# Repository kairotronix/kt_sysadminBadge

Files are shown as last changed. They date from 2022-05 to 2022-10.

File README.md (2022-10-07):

# SysAdmin Badge

This is the PCB design for the SysAdmin Day badge.

The badge design is inspired by deep thought, from The Hitchhiker's Guide to the Galaxy.

The LCD being used is a standard 1.3" 240x240 display from Ali Express. Searching `1.3 inch IPS display TFT LCD 1.3" Display Screen Module 240*240 ST7789 Drive IC SPI HD Full Color for IPS Display Module 240X240` and selecting the "welded" or "soldered" variety will yield the correct board. 

The soldered-on cable was chosen for cost reduction.



# What is the idea
In case of fire, a quick reaction is needed, but if you just woke up, if you are in the bathroom or in any compromising situation, the sysadmin must always respond to the user, and then fix the incident.

For this reason, we have designed a random excuse generator that will give you a perfect SLA, even in desperate moments.

Note: Answers may be satirical, so use at your own risk. 

## History
The System Administrator Appreciation Day, It is celebrated on the last Friday of July since the year 2000.

The holiday was started by a system administrator nicknamed Sleeping Beauty (AS). He got his inspiration from a Hewlett-Packard magazine ad, in which an administrator's co-workers gave him flowers and a fruit basket for setting up their new printers and a pillow to rest on in their spare time.

Wait… what exactly is SysAdmin Day? it’s only the single greatest 24 hours on the planet… and pretty much the most important holiday of the year. It’s also the perfect opportunity to pay tribute to the heroic men and women who, come rain or shine, prevent disasters, keep IT secure and put out tech fires left and right.

At this point, you may be thinking, “Great. I get it. My SysAdmin is a rock star. But now what?” Glad you asked! Proper observation of SysAdmin Day includes (but is not limited to):

Cake & Ice cream

Pizza

Cards

Gifts

Words of gratitude

Custom t-shirts celebrating the epic greatness of your SysAdmin

Balloons

Confetti

Did I say gifts

# Conclusion
Why make one badge electronic? Because is one good gift of your SysAdmin.

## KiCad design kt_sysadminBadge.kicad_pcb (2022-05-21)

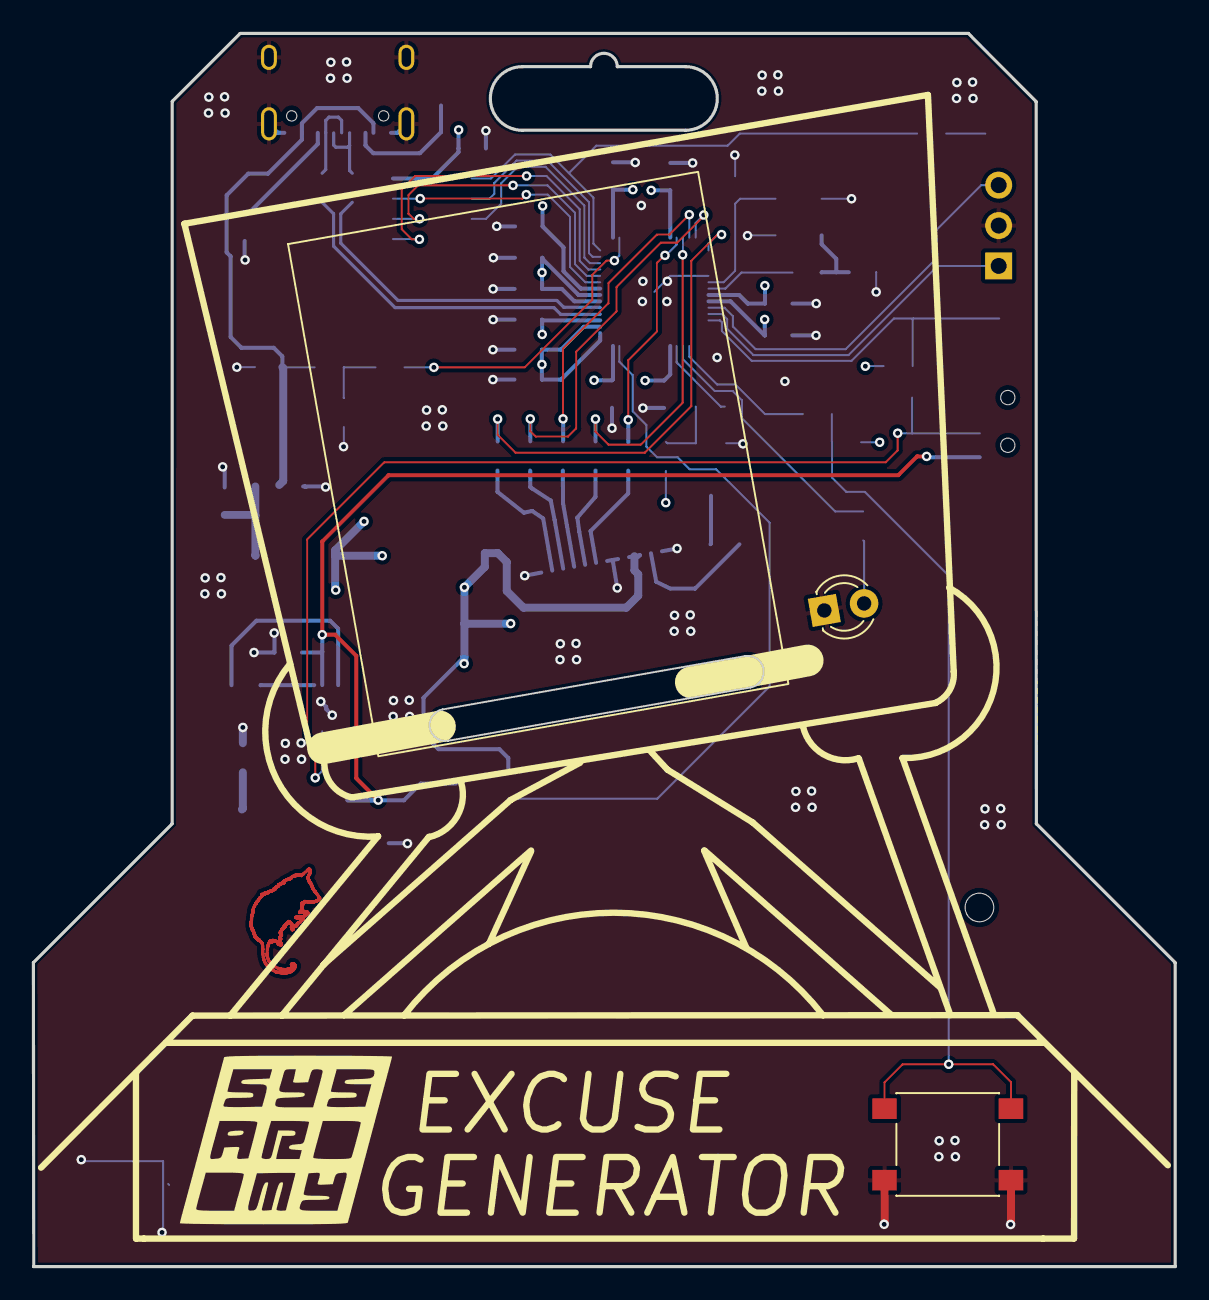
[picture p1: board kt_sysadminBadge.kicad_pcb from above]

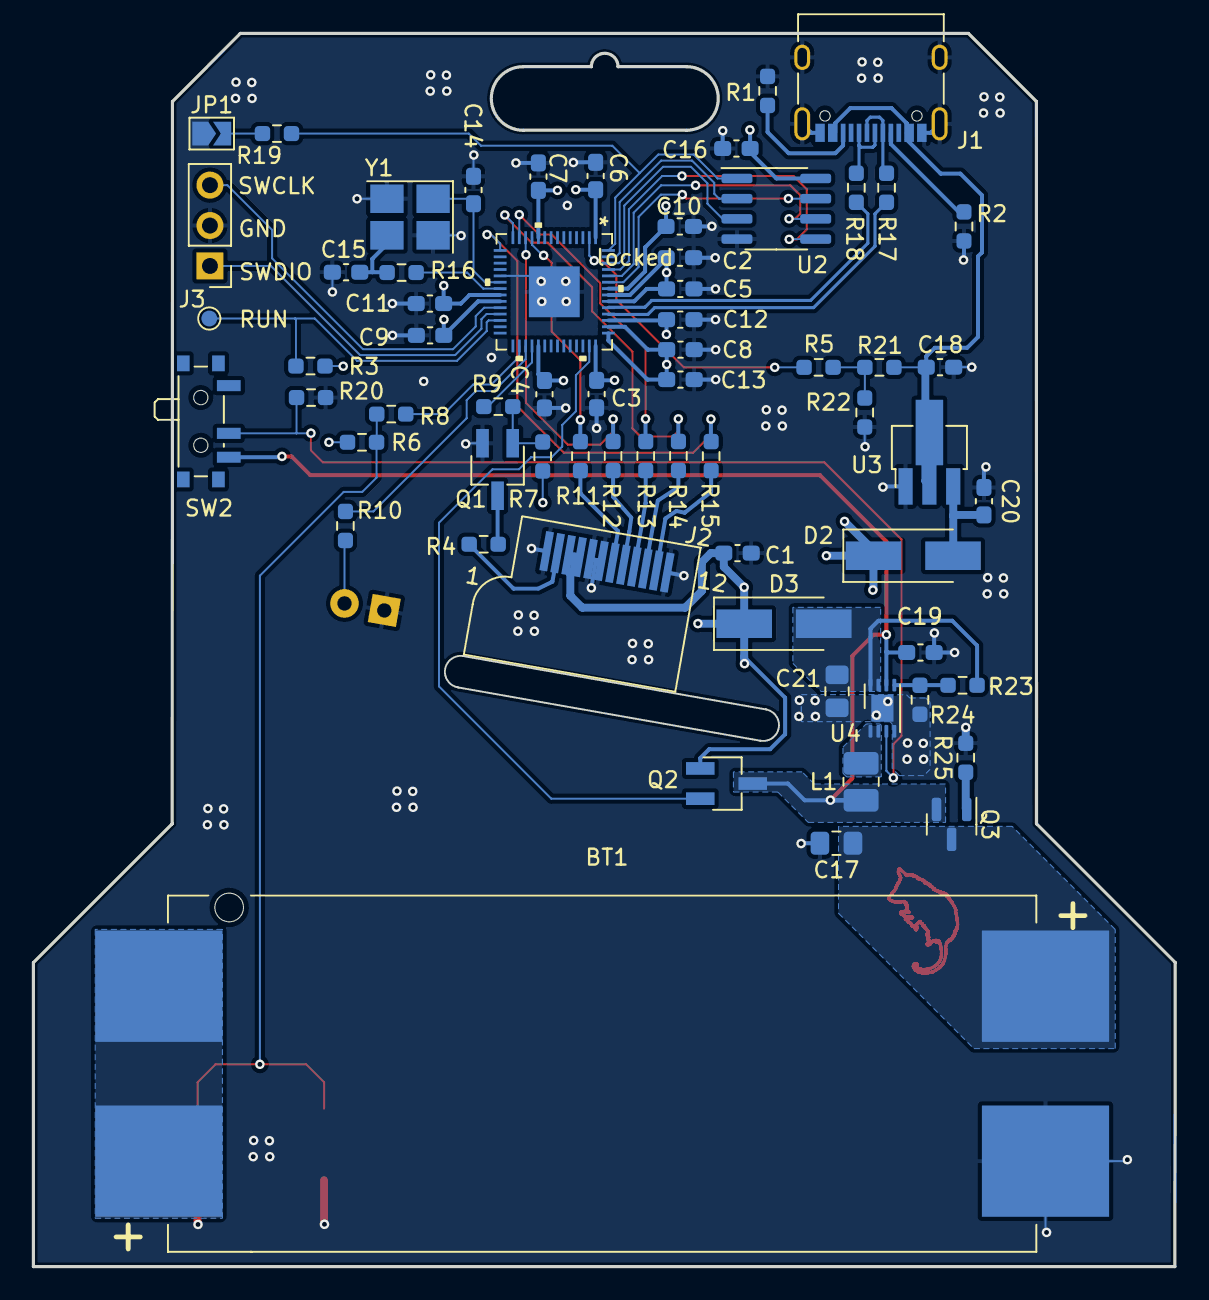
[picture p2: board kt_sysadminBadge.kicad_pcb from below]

Board: 4 copper layers, 71.8 x 77.5 mm, 66 parts (63 on the bottom side), 53 nets.

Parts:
BT1: Battery_4term; BH-AAA-B5AA001
C1, C2, C3, C4, C5, C6, C8, C9, C10, C11, C16: 100nF; C_0603_1608Metric_Pad1.08x0.95mm_HandSolder
C7, C12, C13: 2.2uF; C_0603_1608Metric_Pad1.08x0.95mm_HandSolder
C14, C15: 15pF; C_0603_1608Metric_Pad1.08x0.95mm_HandSolder
C17, C21: 22uF; C_0805_2012Metric_Pad1.18x1.45mm_HandSolder
C18, C19, C20: 1uF; C_0603_1608Metric_Pad1.08x0.95mm_HandSolder
D1: LED; LED_D3.0mm
D2, D3: D_Schottky; D_SMA_Handsoldering
J1: USB_C_Receptacle_USB2.0; USB_C_Receptacle_XKB_U262-16XN-4BVC11
J2: Conn_01x12; st7789-240-240
J3: Conn_01x03; PinHeader_1x03_P2.54mm_Vertical
JP1: Jumper_2_Open; SolderJumper-2_P1.3mm_Open_TrianglePad1.0x1.5mm
L1: 1.5uH; L_1008_2520Metric_Pad1.43x2.20mm_HandSolder
Q1: MMSS8050; SC-59_Handsoldering
Q2: Q_NMOS_GSD; SC-59_Handsoldering
Q3: DMG2301L-7; SOT-23
R1, R2: 5.1kR; R_0603_1608Metric_Pad0.98x0.95mm_HandSolder
R3, R6, R7: 10k; R_0603_1608Metric_Pad0.98x0.95mm_HandSolder
R4: 10R; R_0603_1608Metric_Pad0.98x0.95mm_HandSolder
R5, R8, R11, R12, R13, R14, R15: 0R; R_0603_1608Metric_Pad0.98x0.95mm_HandSolder
R9, R16, R19: 1kR; R_0603_1608Metric_Pad0.98x0.95mm_HandSolder
R10, R25: 330R; R_0603_1608Metric_Pad0.98x0.95mm_HandSolder
R17, R18: 27R; R_0603_1608Metric_Pad0.98x0.95mm_HandSolder
R20, R23: 1MR; R_0603_1608Metric_Pad0.98x0.95mm_HandSolder
R21: 100kR; R_0603_1608Metric_Pad0.98x0.95mm_HandSolder
R22: 150kR; R_0603_1608Metric_Pad0.98x0.95mm_HandSolder
R24: 500kR; R_0603_1608Metric_Pad0.98x0.95mm_HandSolder
SW1: SW_Push; SW_Push_1P1T_NO_6x6mm_H9.5mm
SW2: SW_SPDT; SW_SPDT_PCM12
TP1: TestPoint; TestPoint_Pad_D1.0mm
U2: W25Q16JVSNIQ; SOIC-8_3.9x4.9mm_P1.27mm
U3: HT7336-A; SOT-89-3_Handsoldering
U4: SY7088DGC; DFN-8-1EP_3x2mm_P0.5mm_EP1.7x1.4mm
Y1: 12MHz; Crystal_SMD_3225-4Pin_3.2x2.5mm_HandSoldering
locked: locked; IC57_RP2040

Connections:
/GPIO0: R5.1, locked.2 (GPIO0)
/GPIO8: R11.1, locked.11 (GPIO8)
/GPIO9: R12.1, locked.12 (GPIO9)
/GPIO10: R13.1, locked.13 (GPIO10)
/GPIO11: R14.1, locked.14 (GPIO11)
/GPIO12: R15.1, locked.15 (GPIO12)
/GPIO19: R8.1, locked.30 (GPIO19)
/GPIO20: R10.1, locked.31 (GPIO20)
/GPIO21: R9.1, locked.32 (GPIO21)
/LCD_CLK: J2.9, R13.2
/LCD_CS: J2.8, R12.2
/LCD_DC: J2.7, R11.2
/LCD_DIN: J2.10, R14.2
/LCD_RST: J2.11, R15.2
/LEDK: J2.2, R4.1
/MCU/RUN: R3.2, TP1.1, locked.26 (RUN)
/MCU/SWCLK: J3.3, locked.24 (SWCLK)
/MCU/SWDIO: J3.1, locked.25 (SWDIO)
/MCU/USB_R_D+: R18.2, locked.47 (USB_DP)
/MCU/USB_R_D-: R17.2, locked.46 (USB_DM)
/MCU/USB_STATUS: R5.2, R21.2, R22.1
/MCU/VCC1V1: C9.2, C10.2, C12.1, locked.23 (DVDD), locked.45 (VREG_VOUT), locked.50 (DVDD)
/MCU/VCC3V3: C1.2, C2.2, C3.2, C4.2, C5.2, C6.2, C7.2, C8.2, C11.2, C13.2, C16.1, D2.1 (K), D3.1 (K), J2.3, J2.4, Q2.1 (G), R3.1, R6.2, R7.1, U2.8 (VCC), locked.1 (IOVDD), locked.10 (IOVDD), locked.22 (IOVDD), locked.33 (IOVDD), locked.42 (IOVDD), locked.43 (ADC_AVDD), locked.44 (VREG_VIN), locked.48 (USB_VDD), locked.49 (IOVDD)
/MCU/V_BATT_MEAS: Q2.2 (S), locked.41 (GPIO29/ADC3)
/MCU/XIN: C14.1, Y1.1, locked.20 (XIN)
/MCU/XOUT: R16.2, locked.21 (XOUT)
/MCU/XR: C15.2, R16.1, Y1.3
/Power Management/VCC_3V6_BATT: C21.1, D3.2 (A), R23.1, U4.7 (OUT), U4.8 (OUT)
/Power Management/VCC_3V6_USB: C20.2, D2.2 (A), U3.3 (VOUT)
/Power Management/V_BATT: BT1.2 (+), C17.1, Q3.3 (D)
/Power Management/V_USB: C18.2, J1.A4 (VBUS), J1.A9 (VBUS), J1.B4 (VBUS), J1.B9 (VBUS), R21.1, U3.2 (VIN)
/USB_RAW_D+: J1.A6 (D+), J1.B6 (D+), R18.1
/USB_RAW_D-: J1.A7 (D-), J1.B7 (D-), R17.1
GND: BT1.3 (-), C1.1, C2.1, C3.1, C4.1, C5.1, C6.1, C7.1, C8.1, C9.1, C10.1, C11.1, C12.2, C13.1, C14.2, C15.1, C16.2, C17.2, C18.1, C19.1, C20.1, C21.2, D1.1 (K), J1.A1 (GND), J1.A12 (GND), J1.B1 (GND), J1.B12 (GND), J1.S1 (SHIELD), J2.1, J2.5, J2.6, J2.12, J3.2, JP1.1 (A), Q1.2 (E), R1.2, R2.2, R20.2, R22.2, R24.2, R25.2, SW1.2, U2.4 (GND), U3.1 (GND), U4.4 (SGND), U4.9 (PGND), Y1.2, Y1.4, locked.19 (TESTEN), locked.57 (GND)
unnamed: BT1.1 (-), BT1.4 (+)
unnamed: C19.2, L1.1, Q2.3 (D), Q3.2 (S), SW2.3 (C), U4.6 (IN)
unnamed: D1.2 (A), R10.2
unnamed: J1.A5 (CC1), R2.1
unnamed: J1.B5 (CC2), R1.1
unnamed: JP1.2 (B), R19.1
unnamed: L1.2, U4.1 (LX), U4.2 (LX)
unnamed: Q1.1 (B), R7.2, R9.2
unnamed: Q1.3 (C), R4.2
unnamed: Q3.1 (G), R25.1
unnamed: R6.1, R8.2, SW1.1
unnamed: R19.2, U2.1 (~CS), locked.56 (QSPI_SS_N)
unnamed: R20.1, SW2.2 (B), U4.3 (EN)
unnamed: R23.2, R24.1, U4.5 (FB)
unnamed: U2.7 (~HOLD_~RST_IO3), locked.51 (QSPI_SD3)
unnamed: U2.6 (CLK), locked.52 (QSPI_SCLK)
unnamed: U2.5 (DI_IO0), locked.53 (QSPI_SD0)
unnamed: U2.3 (~WP_IO2), locked.54 (QSPI_SD2)
unnamed: U2.2 (DO_IO1), locked.55 (QSPI_SD1)

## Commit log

2022-05-03 Addming main files
    [MCU_sch.kicad_sch, Power Management.kicad_sch, kt_sysadminBadge.kicad_pcb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]
2022-05-20 Modified resistor value and changed battery holder.
    [MCU_sch.kicad_sch, Power Management.kicad_sch, kt_sysadminBadge.kicad_pcb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]
2022-05-20 reverting to old battery holder (known good)
    [kt_sysadminBadge.kicad_pcb, kt_sysadminBadge.kicad_sch]
2022-05-20 Modifying footprint in sub-schematic page
    [Power Management.kicad_sch]
2022-05-21 Updating design, adding reverse polarity protection
    [MCU_sch.kicad_sch, Power Management.kicad_sch, kt_sysadminBadge.kicad_pcb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]

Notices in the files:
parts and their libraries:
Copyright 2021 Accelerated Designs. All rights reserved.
